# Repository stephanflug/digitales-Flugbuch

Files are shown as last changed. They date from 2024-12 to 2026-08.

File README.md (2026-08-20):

<p align="center">
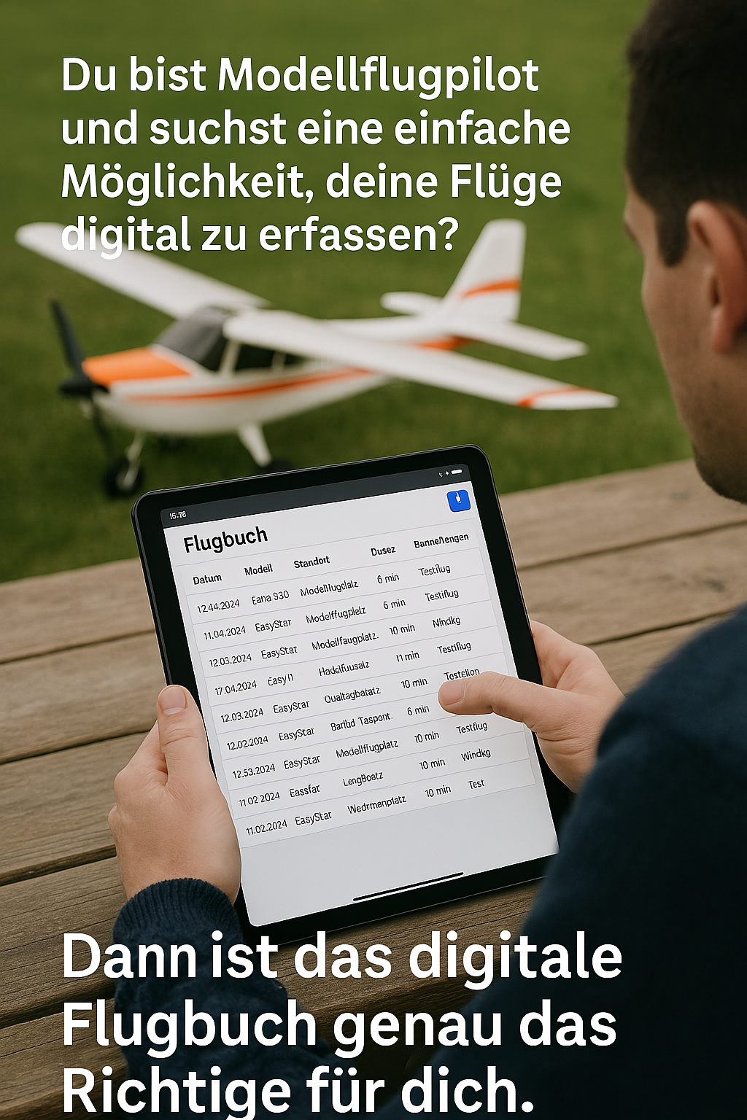
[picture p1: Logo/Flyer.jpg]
  
</p>

<div align="center" width="100%">
    
</div>

# Digitales Flugbuch für Modellflug Vereine

Mit der Software und der Verbindung zu einem Raspberry Pi Zero kann eine digitale Aufzeichnung erstellt werden, die den Anforderungen der aktuellen Verordnung (EU) 2019/947 entspricht.Für Österreich und Deutschland(kann man unter Einstellungen festlegen)

## Kontakt  
Bei Fragen können Sie mich gerne per E-Mail erreichen:  
📧 [steuerung@gmx.at](mailto:steuerung@gmx.at)
oder auch auf dieser Seite [Flugbuch](https://flugbuch.gltdienst.home64.de))

## ⭐ Features

- 🧑‍💼 RFID-Erkennung und Nutzerverifizierung: Wenn ein Benutzer seinen RFID-Chip auf das Lesegerät legt, wird die aktuelle Uhrzeit    zusammen mit dem Namen des Benutzers aus der Benutzerdatei gespeichert. 
- ⌨️ Falls der Benutzer nicht in der Benutzerdatei existiert, wird eine Fehlermeldung ausgegeben.

## ⭐ NEU!

### 🖥️ Flugbuch Cloud Server Panel (Windows) – ab Version 3.9.0

Mit Version **v3.9.0** steht ein neues **Flugbuch Cloud Server Panel für Windows** zur Verfügung.  
Das Panel läuft lokal auf einem Windows-Rechner (z. B. im Vereinsheim) und verbindet sich automatisch mit dem Vereinsflugbuch in der Flugbuch Cloud. Der volle Funktionsumfang des Flugbuchs steht direkt zur Verfügung.

👉 Release-Details:  
https://github.com/stephanflug/digitales-Flugbuch/releases

---

### 🔎 RFID Chip Scanner (Windows & Android)

Zusätzlich zum Flugbuch stehen einfache Hilfstools zum Auslesen der UID von RFID-/NFC-Chips zur Verfügung:

- 🖥️ Windows-Tool für USB-RFID-Lesegeräte  
- 📱 Android-App für NFC-fähige Smartphones  

Die Tools lesen ausschließlich die UID des Chips aus, zeigen sie direkt an und arbeiten vollständig eigenständig.  
Die UID kann im Flugbuch zur eindeutigen Zuordnung von Nutzerchips verwendet werden.

👉 [Zum RFID Chip Scanner](./Tool%20Software/RFID%20Chip%20Scanner/README.md)

---

### 💾 Flugbuch Basic Image

Ein fertiges **Flugbuch Basic Image** steht zum Download bereit.  
Einfach herunterladen und auf die SD-Karte speichern.  
**Bitte unbedingt die Installationsanleitung beachten.**

👉 [Installationsanleitung (PDF)](https://github.com/stephanflug/digitales-Flugbuch/tree/main/Dokumentation/Installation/Flugbuch%20Images)
👉 [Flugbuch Basic Image herunterladen](https://github.com/stephanflug/digitales-Flugbuch/releases)
---

### 📈 Altitude Sensor (ab Version 3.5)

Ab Version **3.5** steht die **Altitude-Sensor-Funktion** zur Verfügung.

👉 [Anleitung (PDF)](https://github.com/stephanflug/digitales-Flugbuch/blob/main/Dokumentation/FlugBuch/RFID%20Flugbuch/Altitude%20Sensor%20beim%20Flugbuch%20einbindenV1.0.pdf)  
👉 Altitude Sensor Projekt: https://github.com/stephanflug/AltitudeSensor

---

### 🧪 Aktuelle getestete Geräte

- ✅ **Pi Zero W2** – getestet  
- ✅ **Pi 3B** – getestet  
- 🔄 **Pi 4** – getestet  
- ⏳ **Pi 5** – getestet

## ⭐ Möglichkeiten:
    -Keinen Cloudzwang
    -Flugbuch-Auswertung direkt auf dem Gerät
    -Möglichkeit, das gesamte Flugbuch zu löschen
    -Flugbuch Einträge bearbeiten
    -Flugbuch-Ausgabe im JSON-Format
    -Flugbuch export in CSV
    -Systeminformationen anzeigen
    -Mail versand
    -Browser Zugang für die Verwaltung
    -Serviceebene direkt auf dem Gerät
    -MQTT
    -MFSD Schnitstelle
    -Kann auch ohne Internet betrieben werden(Nur wenn eine RTC Batterie verbaut wurde)
    -Backup und Restore
    -Viewer Dashboard für eine externen Anzeige via Browser
    -Rest-API Schnitstelle die Flugbuchdaten zu übermitteln
    -Ab der 3.5 Version ist es jetzt möglich einen Altitude Sensor zu verwenden.
    -Bossserver Funktionen.Eine externe Betriebsaufzeichnung auf dem Vereinsserver.
    -VPN Zugang direkt zum Gerät via Flugbuch Cloud Server oder Verein eigenen Server
    -Integration in Areoclub Flugbuch Online
    
<p align="center">
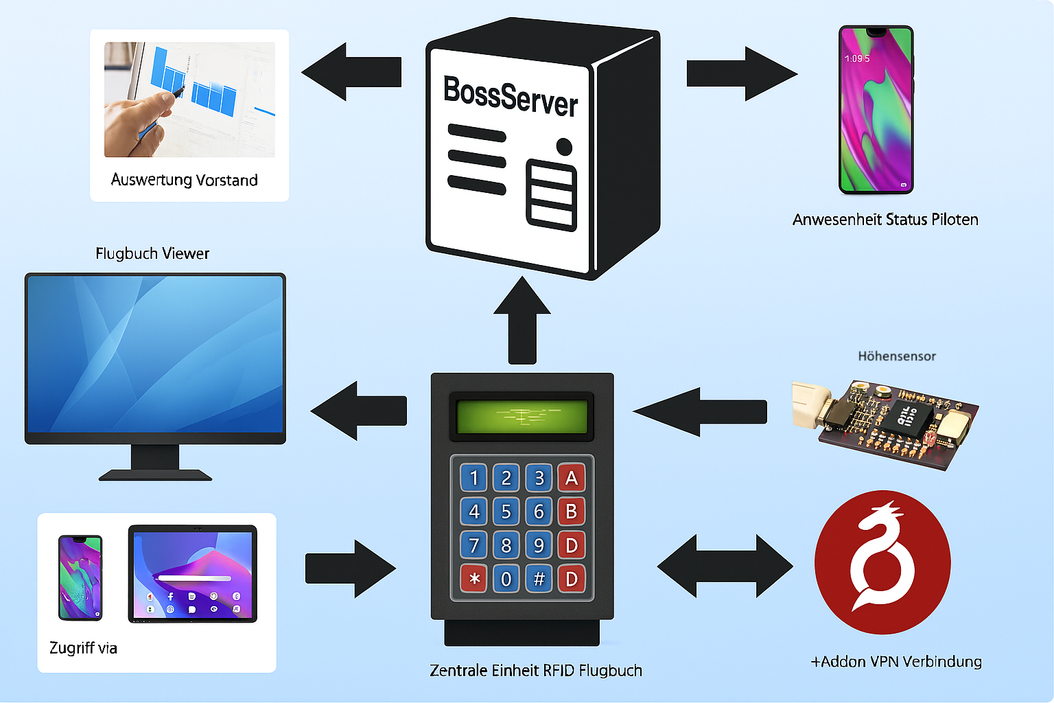
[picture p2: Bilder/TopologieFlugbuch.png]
  
</p>

## 🔧 Vorbereitung: 
```
Benötigte Hardware
- ✅ Raspberry Pi 3 oder höher oder Raspberry Pi 2 Zero. Vereine über 30 User sollten einen Pi 4 verwenden.
- ✅ Speicherkarte (microSD) Kapazität: Mindestens 16 GB, idealerweise 32 GB oder mehr.
- ✅ Ein stabiles und ausreichend starkes Netzteil.
- ✅ Ein Gehäuse 
- ✅ Einen Kühlkörper für den Prozessor.
- ✅ RFID-Modul MFRC522
- ✅ 16-Tasten-Keypad (4x4) mit I2c
- ✅ 1602 LCD-Display mit I2C-Modul
- ✅ RFID-Tags oder -Karten
- ✅ RTC Batterie für den offline Modus(nur wenn das Gerät kein Internet hat)
```
## 🚀 Schnellstart

Verwenden Sie das bereits vorbereitete Image – das spart Zeit und schont die Nerven.

👉 [**Installation: Betriebssystem auf SD-Karte**](https://github.com/stephanflug/digitales-Flugbuch/releases)
👉 [**Doko: Betriebssystem auf SD-Karte**](https://github.com/stephanflug/digitales-Flugbuch/blob/main/Dokumentation/Installation/Flugbuch%20Images/Anleitung_Flugbuch_Images.pdf)  

## 🛠️ Alternative Installation auf einem eigenen Raspberry Pi

Wenn Sie das fertige Image nicht verwenden möchten, können Sie die Software auch manuell auf einem selbst eingerichteten Raspberry Pi installieren.

### ✅ Voraussetzungen

- **Hardware:** Raspberry Pi Zero W2 (oder kompatibles Modell)
- **Betriebssystem:** Vorinstalliertes Linux auf der SD-Karte  
  - **Empfohlen:** Raspberry Pi OS Lite oder Raspberry Pi OS Desktop  
  - **Alternativen:** Ubuntu MATE, DietPi, Arch Linux (sofern kompatibel mit Raspberry Pi)
  -  Speichermedium (SD-Karte) Hochwertige SD-Karte (z. B. SanDisk High Endurance oder Samsung Pro Endurance).

### 📦 Vorbereitung

#### 1. Betriebssystem installieren

Falls noch kein Betriebssystem installiert ist:

- Laden Sie den [**Raspberry Pi Imager**](https://www.raspberrypi.com/software/) herunter.
- Wählen Sie ein geeignetes Linux-Betriebssystem (z. B. Raspberry Pi OS).
- Installieren Sie es auf die SD-Karte.

👉 Eine Schritt-für-Schritt-Anleitung finden Sie in der [offiziellen Raspberry Pi-Dokumentation](https://www.raspberrypi.com/documentation/computers/getting-started.html).

#### 2. Raspberry Pi einrichten

- SD-Karte in den Raspberry Pi einlegen
- Monitor, Tastatur und Maus anschließen
- Gerät starten und überprüfen, ob das System korrekt läuft
- Internetverbindung sicherstellen (WLAN oder Ethernet)

> ⚠️ **Hinweis:** Ohne ein vorinstalliertes Linux-Betriebssystem kann dieses Projekt nicht ausgeführt werden. Bitte stellen Sie sicher, dass das System korrekt installiert und betriebsbereit ist, bevor Sie fortfahren.

###
1. Vorbereitungen nur wenn Docker noch nicht auf dem System installiert wurde sonst weiter mit Postion 3
###  
Als Video ansehen:    <a href="https://github.com/stephanflug/digitales-Flugbuch/blob/main/Installation/Neuinstallation/Video/InstallationVideoFlugBuchsoftware.mp4" target="_blank">Video</a>

Aktualisiere das System:
```
sudo apt update
sudo apt upgrade -y
```

Die empfohlene Methode zur Installation von Docker auf einem Raspberry Pi ist die Verwendung des offiziellen Installationsskripts von Docker, das alle notwendigen Repositorys und Schritte berücksichtigt. 
```
curl -fsSL https://get.docker.com -o get-docker.sh
```
```
sudo sh get-docker.sh
```

2. Docker-Dienst aktivieren
```
sudo systemctl start docker
```
```
sudo systemctl enable docker
```
3.Verzeichniss erstellen für script
```
sudo mkdir -p /opt/digitalflugbuch
```
4.Wechsel dann in das Verzeichnis:
```
cd /opt/digitalflugbuch
```

5a. Herunterladen des Skripts mit wget mit Raspberry Pi 3/4/5 Zero 2W oder höher: Prozessor ARMV7
```
sudo wget -O script.sh https://raw.githubusercontent.com/stephanflug/digitales-Flugbuch/main/script_armv7.sh
```

6. Anmeldeung als root Benutzer wenn das Passwort noch nicht gesetzt wurde mit sudo passwd root
```
su
```

6. Script ausführen.
```
sudo bash script.sh
```
7.Raspi-Config aufrufen
```
sudo raspi-config
```
Menüoptionen von raspi-config
> Interface Options
>Aktivierung von Schnittstellen wie  I2C, SPI

8.Gerät neustarten
```
sudo reboot
```

Beispielablauf:
Das Skript wird heruntergeladen und im aktuellen Verzeichnis gespeichert.
Es wird ausführbar gemacht, sodass du es wie ein Programm starten kannst.
Schließlich wird das Skript ausgeführt, und es erledigt alle im Code definierten Aufgaben.

9. Status prüfen:
```
sudo docker ps
```

10. Danach können Sie die Verwaltungsseite öffnen.
```
Startseite url:http://<IPAdresse>:1880/home
```

11 Schaltplan Prinzipschema:   <a href="https://github.com/stephanflug/digitales-Flugbuch/blob/main/Schaltplan/BelegungsaufstellungV1.0.pdf" target="_blank">Belegungsaufstellung</a>

11a Version 1 mit RFID RC522 (alte Version. Empfehlung:Bei Neuinstallation Version 2 zu verwenden)
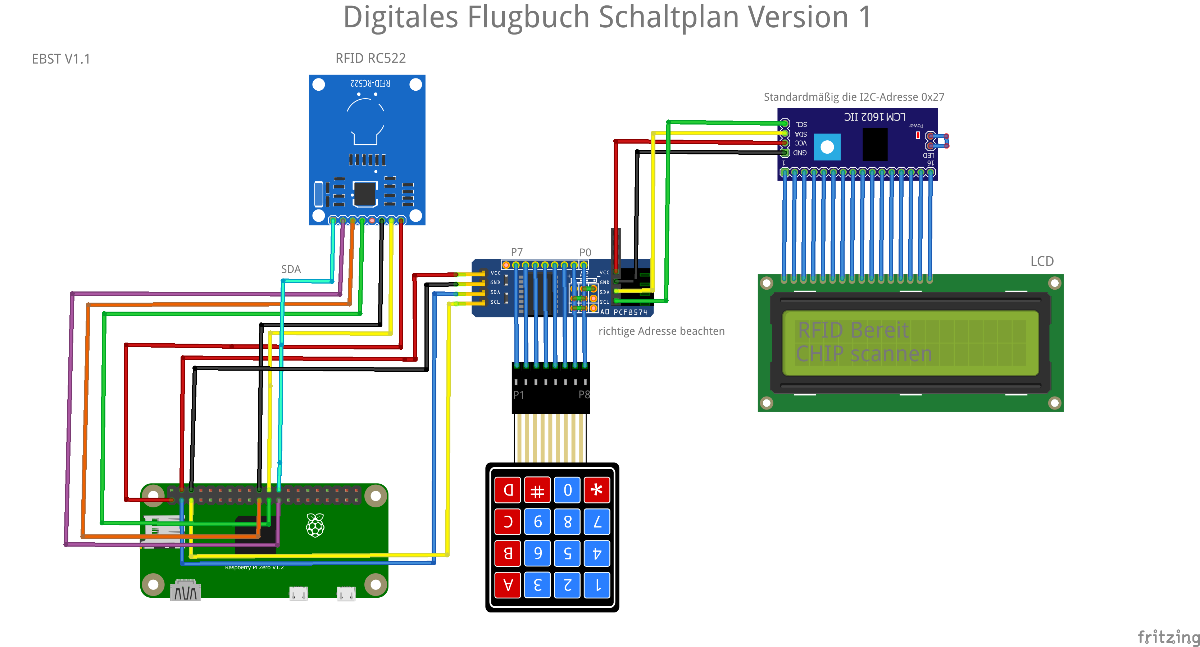
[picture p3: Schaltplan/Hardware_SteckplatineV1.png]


11b Version 1B mit RFID RC522 + RTC
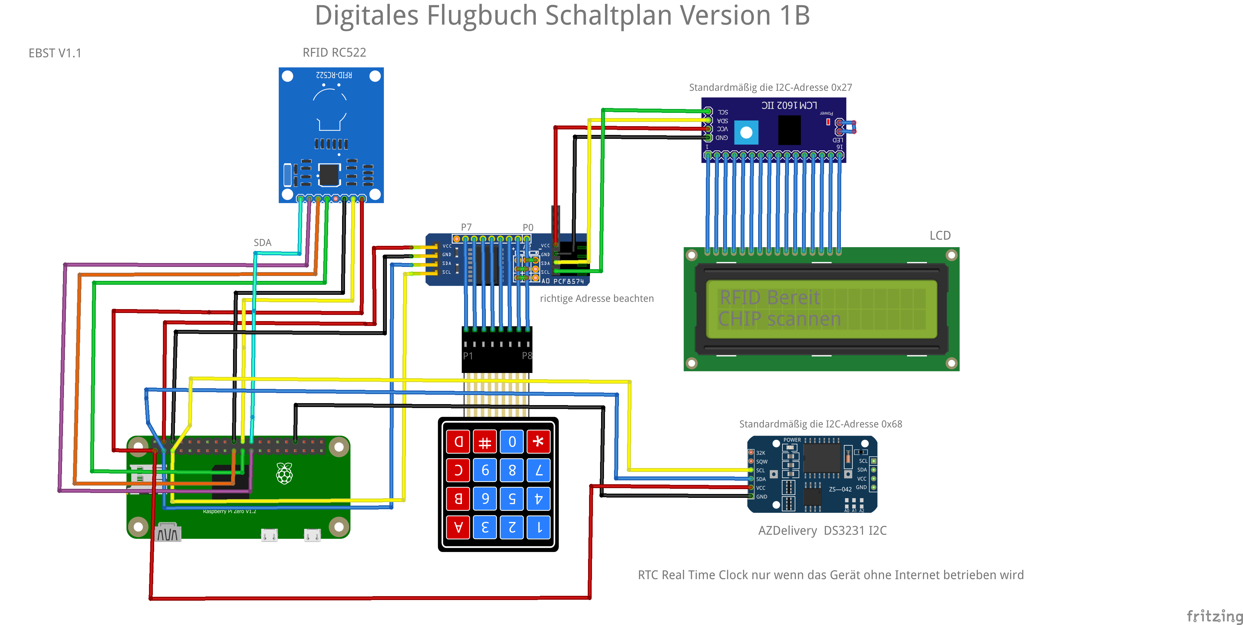
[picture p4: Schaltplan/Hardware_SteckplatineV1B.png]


11c Version 2 mit RFID PN532 + (RTC muss man nicht ausführen wenn das Gerät Internet Zugang hat)
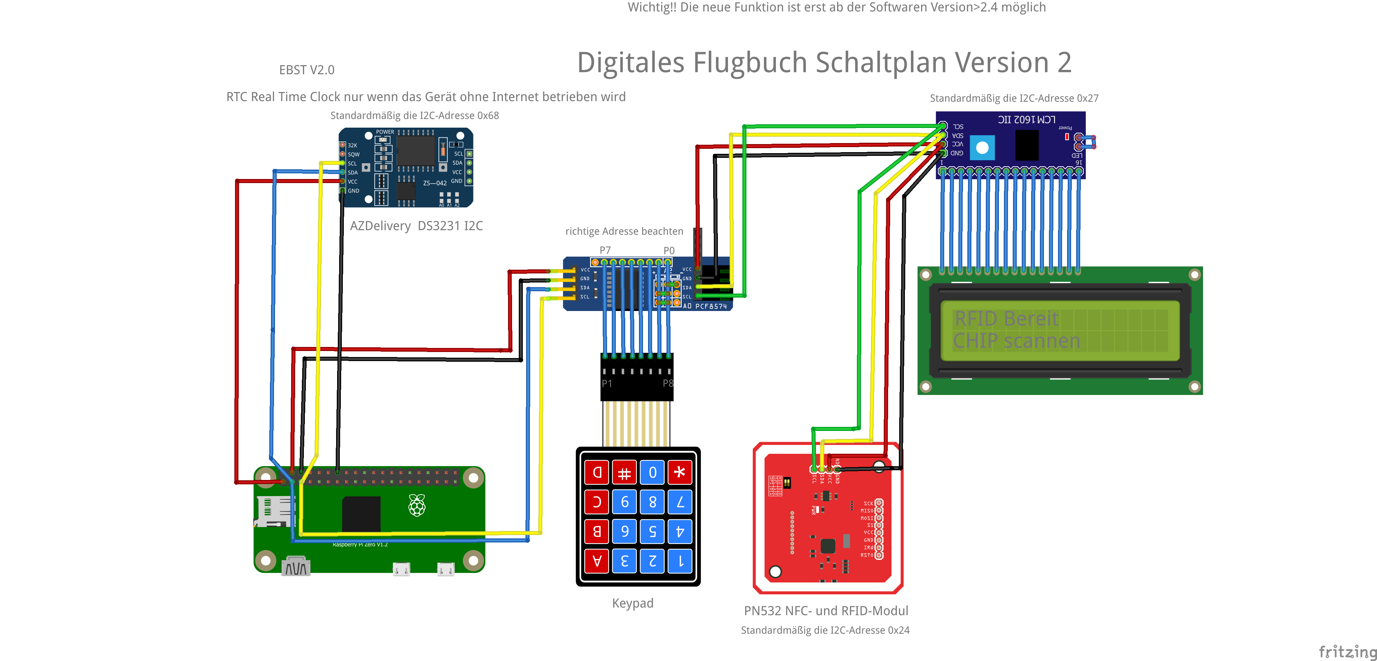
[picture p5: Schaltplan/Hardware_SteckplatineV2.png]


12. Zugriff via Browser: Weitere Bilder Hier: <a href="https://github.com/stephanflug/digitales-Flugbuch/tree/main/Bilder/Webbedienung" target="_blank">Bilder</a>

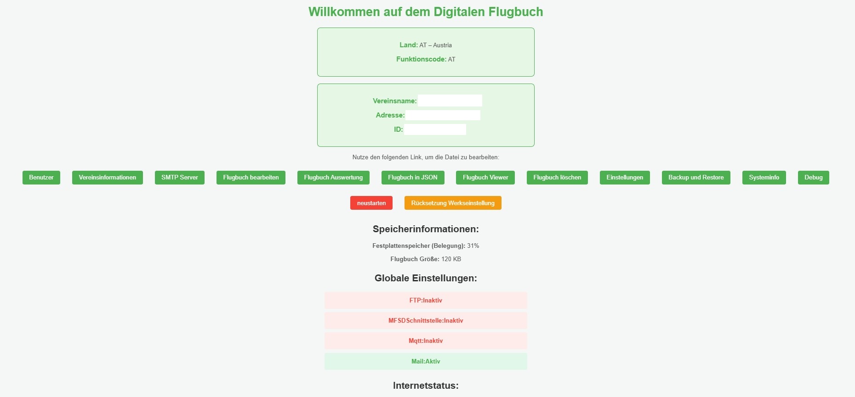
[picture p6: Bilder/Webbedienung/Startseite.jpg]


13. Videos:
<a href="https://www.youtube.com/shorts/2yrWCz5p4jw" target="_blank" rel="noopener noreferrer">
    YouTube Video
</a>

<a href="https://youtu.be/VoY1FuDAuMs" target="_blank" rel="noopener noreferrer">
    YouTube Video
</a>

<a href="https://youtube.com/shorts/nOOInCLnYMw" target="_blank" rel="noopener noreferrer">
    YouTube Video
</a>

<a href="https://youtube.com/shorts/AbHP6MEdS38" target="_blank" rel="noopener noreferrer">
    YouTube Video
</a>

###
1.1 Neues Update einspielen

Hinweis: Wenn Sie bereits das fertige Image verwenden, müssen Sie lediglich die IP-Adresse des Geräts in den Browser eingeben. Sie gelangen dann direkt zur Grundkonfiguration, in der Sie im Menü den Punkt „Flugbuch-Update“ finden.
Diese Schritte sind in diesem Fall nicht mehr erforderlich.

1.2 Wechsel in das Verzeichnis:
```
cd /opt/digitalflugbuch
```
1.3 Herunterladen des Skripts
```
sudo wget -O update_script.sh https://raw.githubusercontent.com/stephanflug/digitales-Flugbuch/main/update_script_armv7.sh
```
1.4  Anmeldeung als root Benutzer
```
su
```

1.5. Script ausführen.
```
sudo bash update_script.sh
```
1.6.Gerät neustarten
```
sudo reboot
```

### ☕ Unterstütze das Büro-Kaffeekonto!

Damit der Kaffee im Büro nie ausgeht und die Entwicklung weiter auf Hochtouren läuft, freuen wir uns über eine kleine Unterstützung. ☕💻

Jeder Beitrag hilft dabei, die Kaffeemaschine am Laufen zu halten und sorgt für genügend Energie für neue Ideen, Funktionen und Updates.



**☕ [Kaffee via PayPal spendieren](https://paypal.me/stephanflug)**

Vielen Dank für deine Unterstützung! ❤️

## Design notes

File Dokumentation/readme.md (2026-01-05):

# RFID-Flugbuch – Dokumentation

Dieses Repository dient als zentrale Anlaufstelle für Hinweise, Releases und Verweise rund um das **RFID-Flugbuch** (inkl. Service-Menü, Systemkonfiguration, Add-ons und Inbetriebnahme).

Die **vollständige Dokumentation** finden Sie hier:

## 📚 Online-Dokumentation
👉 https://doko.flugbuch.gltdienst.home64.de/share/hiv8kxsvqf/p/servicemenue-geraet-xMON4uZUVv

---

## Inhalt (Kurzüberblick)
In der Online-Dokumentation finden Sie unter anderem:

- **Gerätebedienung** (Anmeldung/Abmeldung, Eingaben über Keypad)
- **Service-Menü** (Statusanzeigen, IP, WLAN, Version, Neustart, Sensoranzahl)
- **Weboberfläche / Admin-Funktionen** (Benutzer, Vereinsdaten, Flugbuch-Management, Auswertung, Backup/Restore)
- **Add-ons** (z. B. WireGuard-Client, Healthcheck, Systemupdate)
- **Altitude Sensor** (Einbindung via MQTT, Prüfung im Service-Menü)
- **Inbetriebnahme & Debug** (I²C-Scan, Systemwerte, Diagnose)

---

## Änderungen / Releases
Änderungen und Versionen werden über die GitHub-Releases bzw. die Dokumentation nachvollziehbar gemacht.

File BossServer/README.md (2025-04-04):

# **Flugdaten Auswertungs- und Login-System**

Dieses Projekt umfasst zwei wesentliche Komponenten: ein sicheres **Login-System** und eine **Flugdaten-Auswertungsseite**. Die Benutzer können sich anmelden, um auf Flugdaten zuzugreifen und diese zu analysieren. 

## **Code 1: Login-System**

Das Login-System gewährleistet einen sicheren Zugriff auf die Flugdaten. Benutzer müssen sich mit einem Benutzernamen und Passwort anmelden, bevor sie auf die Auswertungsseite zugreifen können. 

### **Funktionen:**
- **Sichere Session-Verwaltung:** 
  - Erneuert die Session-ID nach dem Login, um Session-Hijacking zu verhindern.
  - Stellt sicher, dass die Cookies nur über HTTPS gesendet werden und JavaScript nicht darauf zugreifen kann.
- **Benutzerauthentifizierung:** 
  - Überprüft Benutzernamen und Passwort gegen eine vordefinierte Liste in einer externen Datei (`users.php`).
  - Bei erfolgreichem Login wird der Benutzer zur Seite mit den Flugdaten weitergeleitet. Bei Fehlern wird eine Fehlermeldung angezeigt.
- **Responsives Design:** 
  - Ein benutzerfreundliches Login-Formular, das auf allen Geräten gut aussieht.

### **Verwendete Technologien:**
- PHP für die Server-seitige Logik.
- HTML, CSS für das Frontend.

---

## **Code 2: Flugdaten Auswertung und Filterung**

Nach dem erfolgreichen Login können Benutzer Flugdaten einsehen, filtern und analysieren. Diese Seite bietet eine detaillierte Auswertung der Flugdaten, basierend auf RFID und Benutzernamen.

### **Funktionen:**
- **Zugriffsprüfung:** 
  - Stellt sicher, dass nur angemeldete Benutzer auf die Auswertungsseite zugreifen können.
- **Datenanalyse:** 
  - Flugdaten werden aus mehreren JSON-Dateien geladen und zusammengeführt.
  - Eine statistische Auswertung zeigt die Anzahl der Flüge pro Benutzer.
  - Detaillierte Informationen zu jedem Flug wie Startzeit, Endzeit und Flughöhe werden angezeigt.
- **Filterfunktionen:** 
  - Ermöglicht das Filtern der Flugdaten nach **RFID** und **Benutzernamen**.
- **Grafische Darstellung:** 
  - **Chart.js** wird verwendet, um die Anzahl der Flüge pro Benutzer in einer interaktiven Balkengrafik darzustellen.
- **PDF-Export:** 
  - Die Möglichkeit, die Flugdaten und die erstellte Grafik als PDF herunterzuladen.

### **Verwendete Technologien:**
- PHP für die Backend-Logik.
- **Chart.js** für die Erstellung interaktiver Diagramme.
- **jsPDF** für den Export von Daten als PDF.

---

## **Technische Details und Anforderungen**

### **Sicherheitsvorkehrungen im Login:**
- **Session-Hijacking-Schutz:** 
  - Das Session-Cookie ist **HTTPOnly** und wird nur über **HTTPS** gesendet.
  - **Session-Regenerierung** sorgt dafür, dass die Session-ID nach der Anmeldung geändert wird.
  
### **Flugdatenverarbeitung:**
- Die Flugdaten werden aus Dateien im JSON-Format geladen und aufbereitet.
- **RFID- und Benutzernamenfilter:** 
  - Ermöglicht das gezielte Filtern von Flugdaten basierend auf RFID und Benutzernamen.
  
### **Datenvisualisierung:**
- Mit **Chart.js** werden Flugdrafiken erstellt, um die Verteilung der Flüge übersichtlich darzustellen.
- Die Tabelle zeigt detaillierte Fluginformationen, einschließlich **Flughöhe** und **Luftraumbeobachter**.

---

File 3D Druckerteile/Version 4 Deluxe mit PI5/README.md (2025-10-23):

# 📦 Raspberry Pi 5 Gehäuse mit digitalem Flugbuch & RFID-Chip

Ein maßgeschneidertes Gehäuse für den **Raspberry Pi 5** – optimiert für den Einsatz mit dem **digitalen Flugbuch** und integriertem **RFID-Chip**.  
Optional mit **PG16-Kabeldurchführung** (oben oder unten).

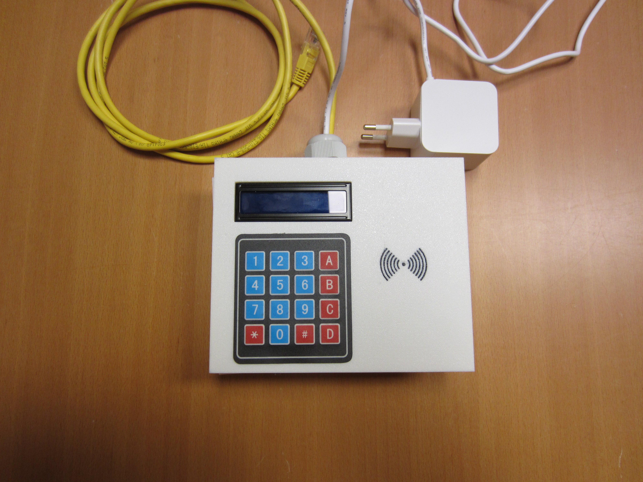
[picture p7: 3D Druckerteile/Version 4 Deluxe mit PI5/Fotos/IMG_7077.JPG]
Gehäuse mit RFID und Display


---

## ⚙️ Features

📗 Passend für Raspberry Pi 5  
📘 Öffnungen für Display und RFID-Modul  
🔩 PG16-Kabeldurchführung wahlweise oben oder unten  
🧊 Kompatibel mit Einschmelzmuttern (M2 × 4 mm)  
🖨️ Optimiert für FDM-Druck mit PETG oder PLA  

---

## 🔧 Hinweise zur Montage

### 🕳️ Bohrungen & Befestigung
- 🔩 **4 × Schrauben Ø 4–4,5 mm** – zur Gehäusemontage  
- 🧷 **M2 × 4 mm Einschmelzmuttern** – für Innenbefestigungen  
- ⚙️ Einschmelzmuttern bei *Deckel 1* **nicht möglich** (durchgehende M2-Schrauben verwenden)

---

### 🧱 Material & Druckparameter
- **Material:** PETG (Außenmontage) oder PLA (Innenmontage)  
- **Drucker:** Bambu Lab P1S / X1C mit AMS  
- **Layerhöhe:** 0,2 mm  
- **Infill:** 20–30 %  
- **Supports:** Nur bei Bedarf  

---

## 🧩 STL-Dateien

### 🔖 Logo
- `Logo.stl`

### 🧱 Gehäuseboden
- `Gehäuse_PG16_oben.stl`  
- `Gehäuse_PG16_unten.stl`

### 🧰 Gehäuse 1 – Deckel
- 📺 **Display-Ausschnitt:** 73,5 mm × 27,5 mm  
- 🔩 **4 × M2-Schrauben (durchgehend)**  
- `Deckel_1_mit_Logo.stl`  
- `Deckel_1_ohne_Logo.stl`

### 🧰 Gehäuse 2 – Deckel
- 📺 **Display-Ausschnitt:** 71,5 mm × 25,0 mm  
- `Deckel_2_mit_Logo.stl`  
- `Deckel_2_ohne_Logo.stl`

### 🧰 Gehäuse 3 – Deckel
- 📺 **Display-Ausschnitt:** 72,0 mm × 25,8 mm  
- `Deckel_3_mit_Logo.stl`  
- `Deckel_3_ohne_Logo.stl`

---

## 🧑‍🔬 Autor

Erstellt und getestet von **Thomas Behmer** 🛠️

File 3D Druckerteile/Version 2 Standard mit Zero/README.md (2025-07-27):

# 📦 Raspberry Pi Zero W2 Gehäuse mit RFID und Display

Ein maßgeschneidertes Gehäuse für den Raspberry Pi Zero W2 – mit Halterungen für ein RFID-Modul, ein Display sowie Belüftung für einen Kühlkörper.

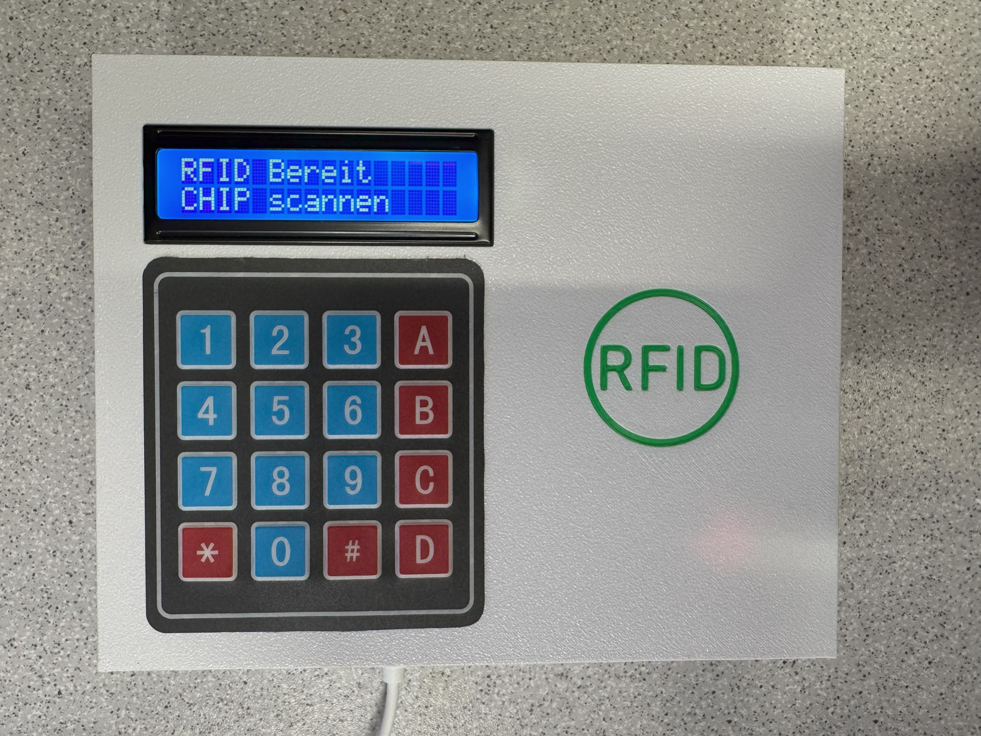
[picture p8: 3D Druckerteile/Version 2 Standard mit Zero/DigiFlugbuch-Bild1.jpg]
Gehäuse mit RFID und Display


---

## ⚙️ Features

📗 Platz für Raspberry Pi (mit Kühlkörper)  
📘 Montagemöglichkeiten für RFID-Modul & Display  
🧊 Kompatibel mit Geekworm-Kühlkörpern  
🧷 Unterstützung für eingeschmolzene Gewindeeinsätze  
🖨️ Optimiert für FDM-Druck mit PETG  

---

## 🔧 Hinweise zur Montage

### 🕳️ Bohrungen
- 🔩 **M3** – für RFID-Modul, Display und Gehäusedeckel  
- 🔩 **M2.5** – zur Befestigung des Raspberry Pi mit Kühlkörper  

### 🧊 Kühlkörper
Ich verwende diesen Kühlkörper von Geekworm (Amazon):  
👉 `B09QMBCXLB` auf Amazon

### 🖨️ 3D-Druck
- Material: **PETG**  
- Drucker: **Bambu Lab P1S mit AMS**  
- Layerhöhe: **Empfohlen: 0.2 mm**  
- Infill: **15–25 %**  
- Supports: **Nur bei Bedarf**  

Die Schrauben werden direkt ins Material eingedreht (alternativ Gewindeeinsätze verwenden).

---

## 🔥 Gewindeeinsätze (eingeschmolzen)
- 🧷 **M2.5** – für die Befestigung des Raspberry Pi  
- 🧷 **M3** – zur Verschraubung des Gehäusedeckels  

---

## 🧑‍🔬 Autor

Erstellt und getestet von **Christoph Figl** 🛠️

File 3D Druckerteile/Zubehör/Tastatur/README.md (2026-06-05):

# Tastatur-Abdeckung für 4x4 Matrix-Keypad

Dieses Verzeichnis enthält eine 3D-druckbare Abdeckung für eine 4x4 Matrix-Tastatur. Die Abdeckung ist als Zubehör für das digitale Flugbuch gedacht und kann zur sauberen Montage eines 16-Tasten-Keypads verwendet werden.

## Dateien

| Datei | Beschreibung |
|---|---|
| [`Tastatur Abdeckung.stl`](./Tastatur%20Abdeckung.stl) | STL-Datei für den 3D-Druck der Tastatur-Abdeckung. |
| [`4x4_Keypad_Tastatur_Datenblatt_AZ-Delivery_Vertriebs_GmbH.pdf`](./4x4_Keypad_Tastatur_Datenblatt_AZ-Delivery_Vertriebs_GmbH.pdf) | Datenblatt des verwendeten 4x4 Matrix-Keypads mit technischen Daten, Pinout und Anschlussbeispielen. |

### Anschlussbelegung

| Alter Anschluss / Steuerung | Neue 4x4-Tastatur |
|---:|---:|
| 1 | 5 |
| 2 | 6 |
| 3 | 7 |
| 4 | 8 |
| 5 | 1 |
| 6 | 2 |
| 7 | 3 |
| 8 | 4 |



## Verwendungszweck

Die Abdeckung dient dazu, das 4x4 Keypad mechanisch sauber in ein Gehäuse oder Bedienfeld zu integrieren

## Montage

1. STL-Datei im Slicer öffnen.
2. Druckausrichtung und Skalierung prüfen.
3. Abdeckung drucken.
4. Druckteil entgraten und Passform mit dem Keypad testen.
5. Keypad einsetzen und mechanisch befestigen.
6. Anschlussleitungen gemäß Pinout oder eigenem Schaltplan verbinden.
7. Funktionstest jeder Taste durchführen.

## Sicherheitshinweise

- Vor dem Anschluss Spannungsversorgung trennen.
- Keine GPIO-Pins des Raspberry Pi mit 5 V oder 24 V beaufschlagen.
- Pinout vor dem Einschalten prüfen.
- Kurzschlüsse durch offene Kontakte oder falsch gesteckte Leitungen vermeiden.

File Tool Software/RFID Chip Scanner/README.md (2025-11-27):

# 🔎 RFID Chip Scanner – Windows & Android

## 📘 Übersicht

Dieser Ordner enthält zwei kompakte Hilfstools, die ausschließlich dazu dienen, die **UID (Unique ID) von RFID-Chips** auszulesen:

- 🖥️ **Windows-Tool** für USB-RFID-Lesegeräte  
- 📱 **Android-App** für NFC-fähige Smartphones  

Die ermittelten UID-Werte können unter anderem im **Digitalen Flugbuch** verwendet werden, um Nutzerchips eindeutig zuzuordnen. Die Tools arbeiten **komplett eigenständig** und greifen **nicht** auf das Flugbuchsystem zu.

---

## 🎯 Funktionsumfang

- 🔐 Auslesen der **UID** eines RFID-Chips  
- 👁️ Klare, direkte Anzeige der UID  
- 📋 Möglichkeit zum Kopieren oder Notieren der UID  

> ℹ️ Beide Tools sind bewusst schlicht gehalten und fokussieren sich auf zuverlässiges, unkompliziertes UID-Auslesen.

---

## 🖥️ Windows-Tool

### Eigenschaften
- ✔️ Unterstützt Windows 10 und 11  
- ✔️ Funktioniert mit gängigen **USB-RFID-Readern**  

### Anwendung
1. 🔌 USB-RFID-Leser anschließen  
2. ▶️ Windows-Tool starten  
3. 🪪 RFID-Chip auflegen  
4. 📄 UID wird sofort angezeigt  

---

## 📱 Android-App

### Eigenschaften
- ✔️ Für Android-Geräte mit **NFC-Unterstützung**  
- ✔️ Nutzt den integrierten NFC-Sensor des Smartphones  

### Anwendung
1. 📥 App installieren  
2. 📡 NFC aktivieren  
3. ▶️ App starten  
4. 🪪 Chip an die Rückseite des Geräts halten  
5. 📄 UID erscheint direkt auf dem Display  

---

## 👨‍💻 Softwareentwicklung

**Entwickelt von: Thomas Behmer**

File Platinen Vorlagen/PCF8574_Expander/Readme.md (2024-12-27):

Platinen-Layout ist mit "Eagle 7" gemacht , die e12 Datei im Isolationsfräsen mit "Estlcam 12"

von Manfred Stratmann

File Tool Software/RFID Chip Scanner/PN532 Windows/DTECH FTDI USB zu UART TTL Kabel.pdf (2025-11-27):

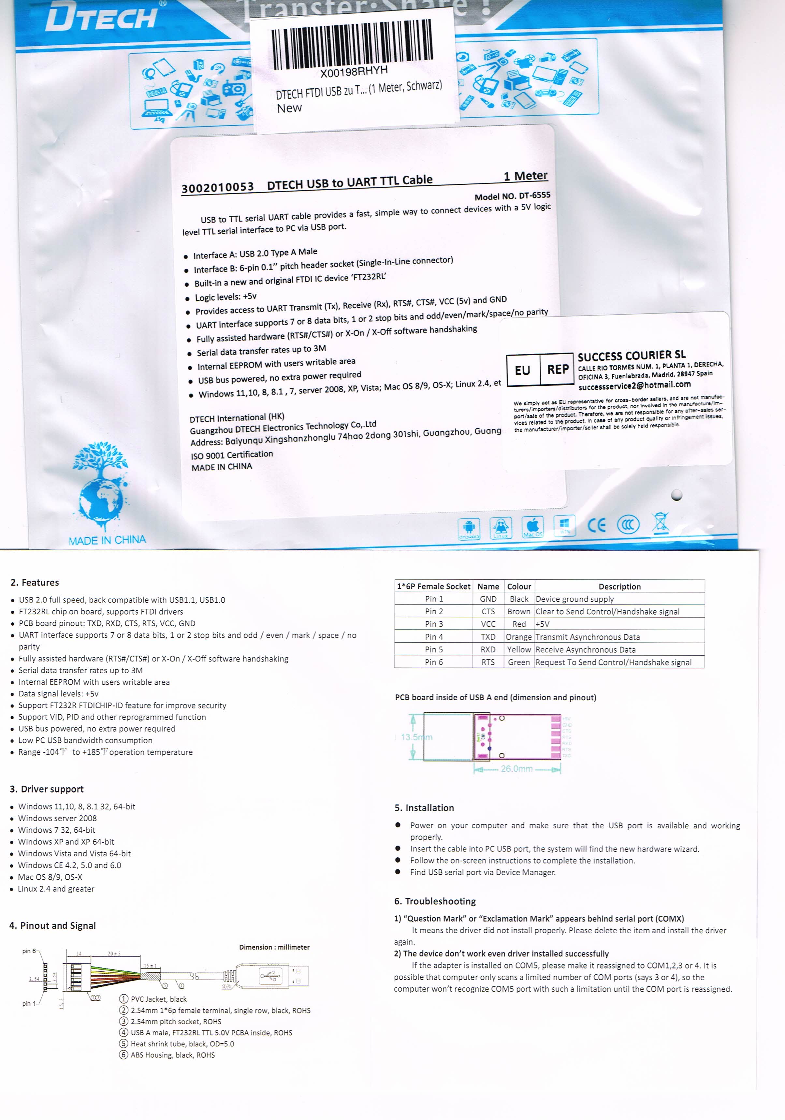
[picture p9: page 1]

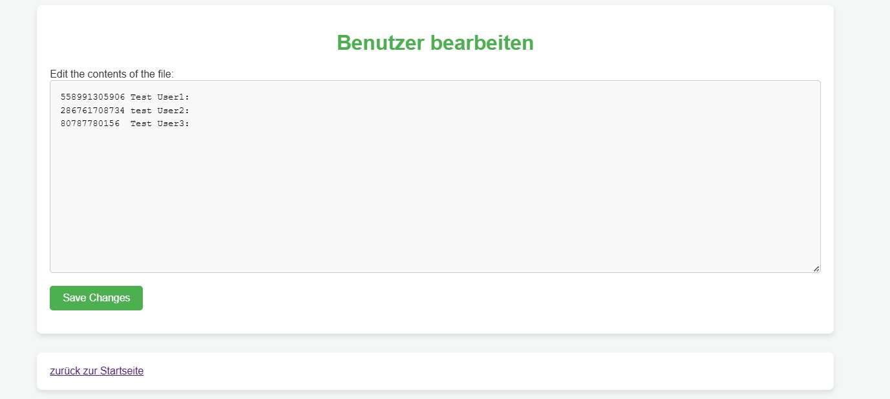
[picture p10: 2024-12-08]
Bilder/Webbedienung/Benutzer.jpg

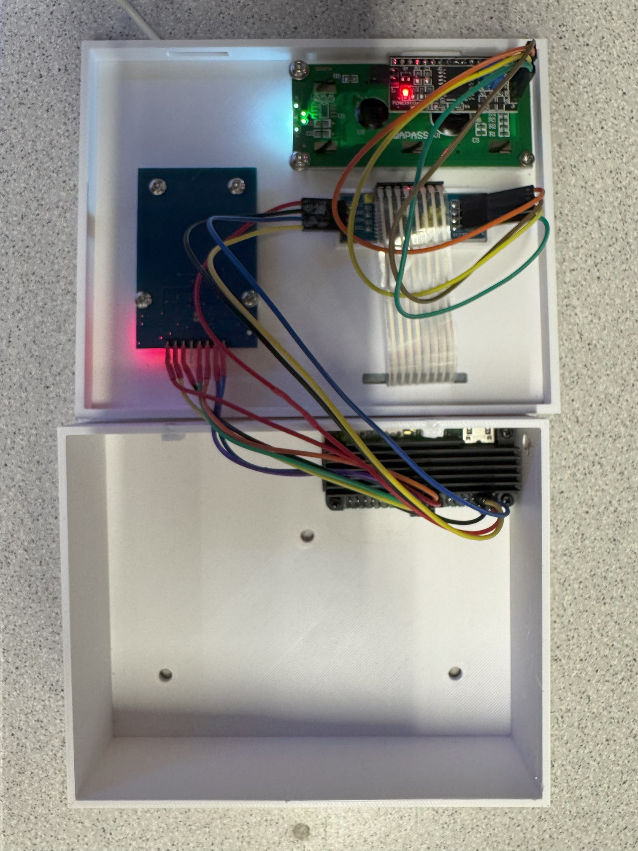
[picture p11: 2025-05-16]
3D Druckerteile/Version 2 Standard mit Zero/DigiFlugbuch-Bild2.jpg

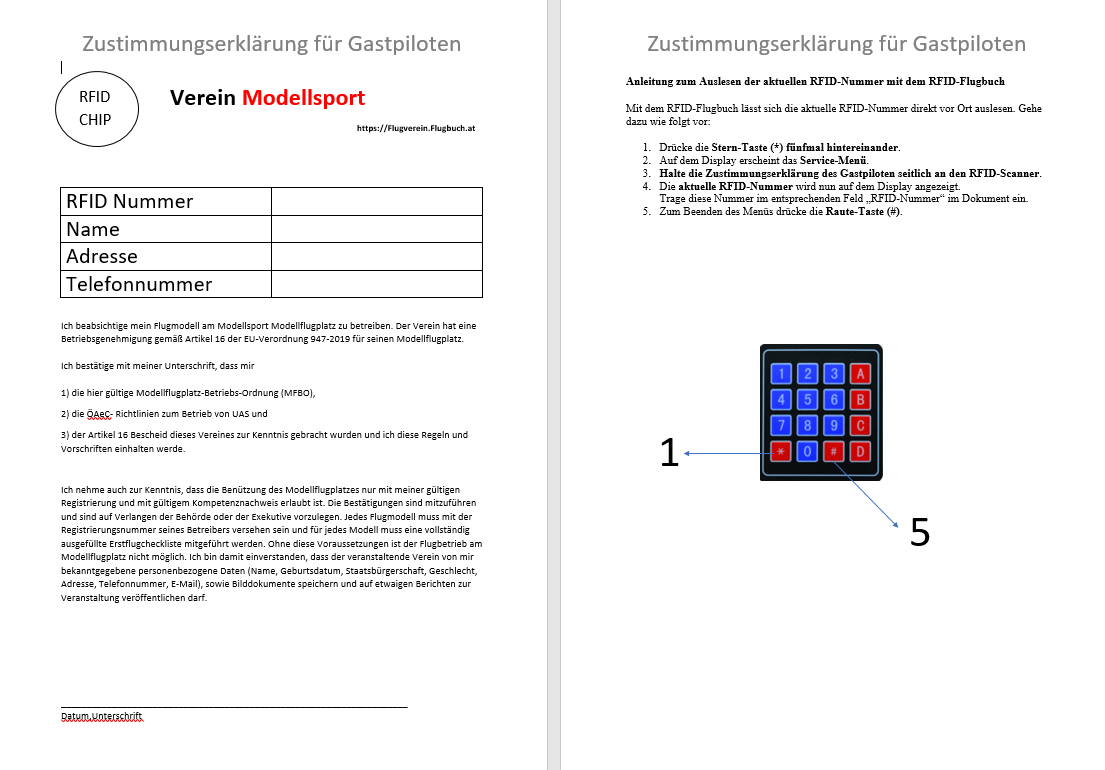
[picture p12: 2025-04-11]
Formulare/Gastpiloten/Bild Formular Gastpilot.png

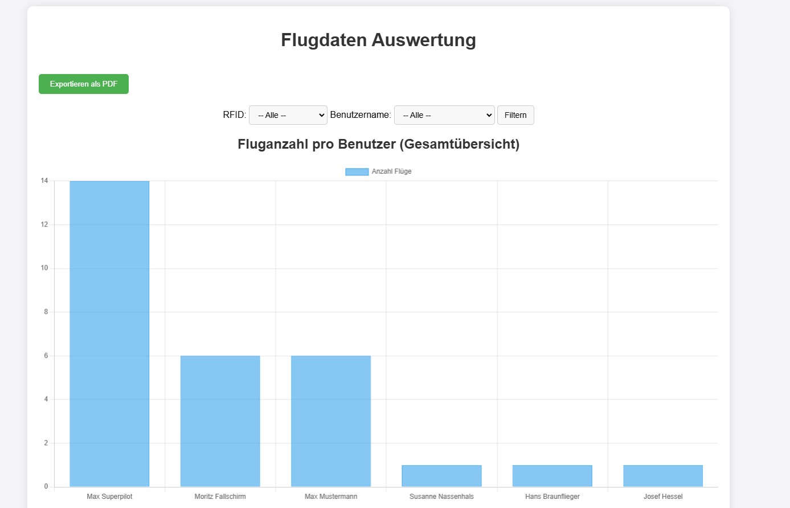
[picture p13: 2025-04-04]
BossServer/V1/Bilder/Flugdaten Auswertung.jpg

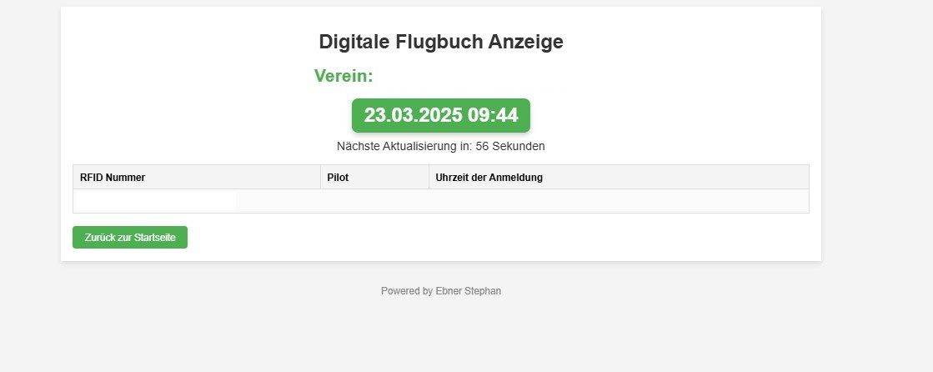
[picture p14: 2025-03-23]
Bilder/Webbedienung/Flugbuch Viewer.jpg

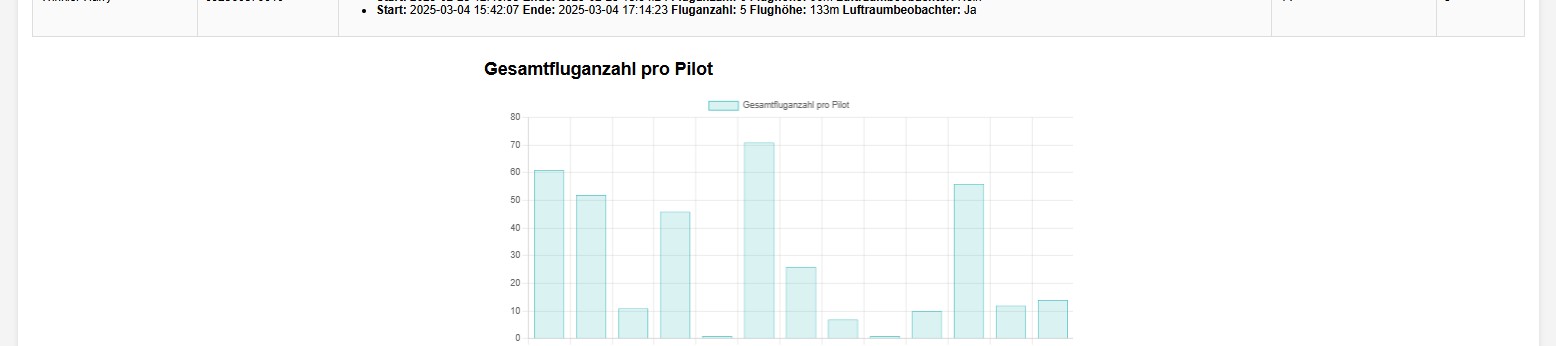
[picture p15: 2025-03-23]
Bilder/Webbedienung/Flugbuch Auswertung_2.jpg

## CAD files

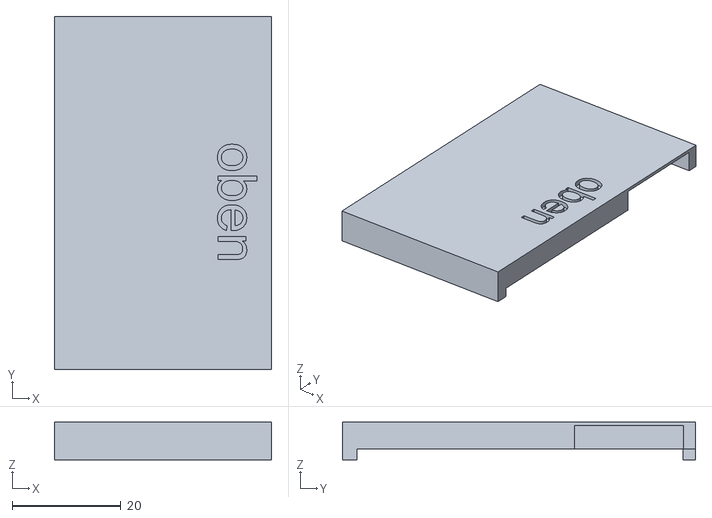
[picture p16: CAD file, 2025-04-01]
3D Druckerteile/Version 1 Basic mit Zero/RC522V1.stl
40.0 x 65.0 x 6.94

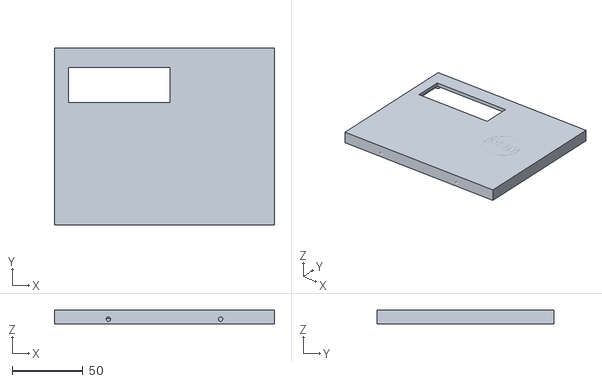
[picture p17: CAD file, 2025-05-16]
3D Druckerteile/Version 2 Standard mit Zero/DigiFlugbuch Oberteil.stl
155.0 x 125.0 x 10.0

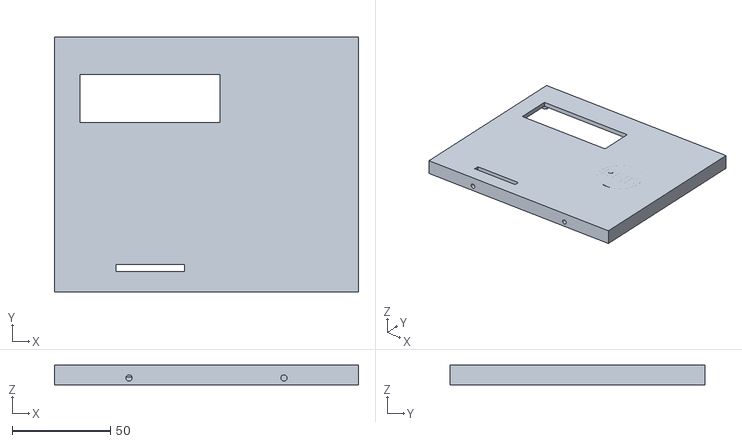
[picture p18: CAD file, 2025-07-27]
3D Druckerteile/Version 3 Deluxe mit PI4/DigiFlugbuch Rpi4 outdoor Deckel.stl
155.0 x 130.0 x 10.0

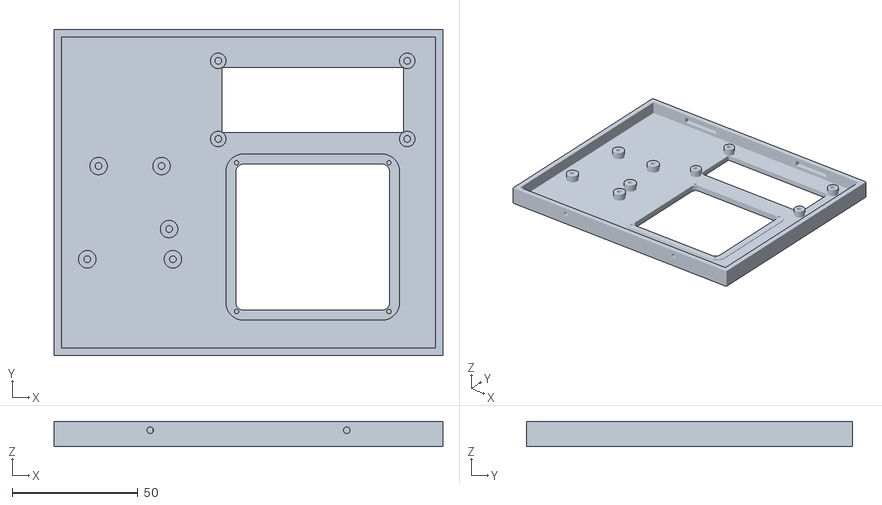
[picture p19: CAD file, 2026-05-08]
3D Druckerteile/Version 4 Deluxe mit PI5/Deckel_3_angepasst_neue_Tastatur.stl
154.4 x 129.4 x 10.0

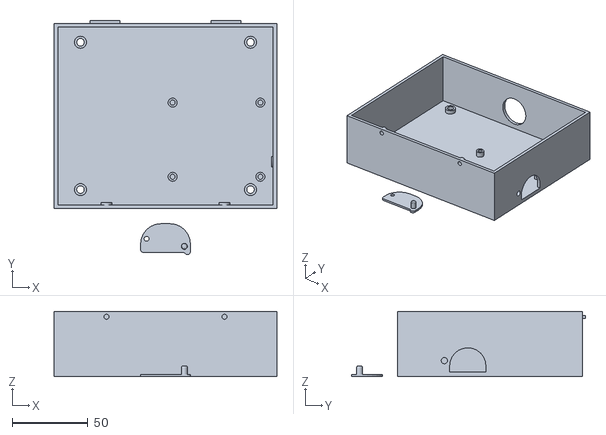
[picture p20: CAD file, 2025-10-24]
3D Druckerteile/Version 4 Deluxe mit PI5/mit SD Karten Serviceklappe/Gehäuse_PG16_oben+.stl
147.4 x 154.9 x 43.0

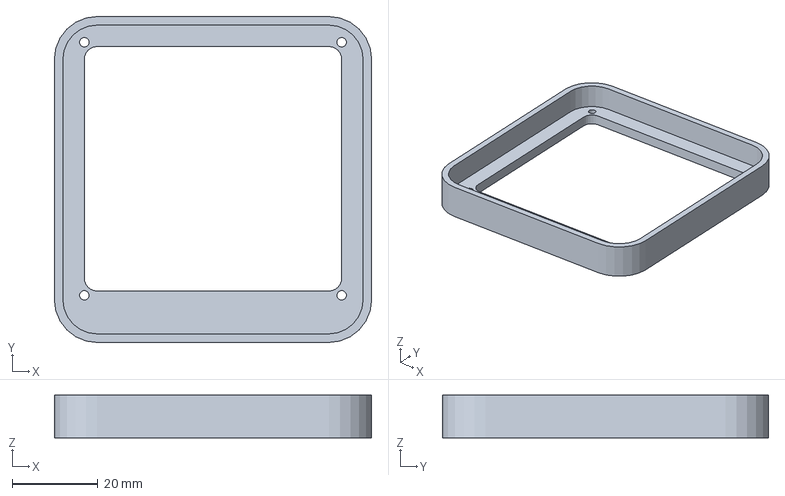
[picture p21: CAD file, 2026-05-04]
3D Druckerteile/Zubehör/Tastatur/Tastatur Abdeckung.3mf
74.0 x 76.0 x 10.0 mm

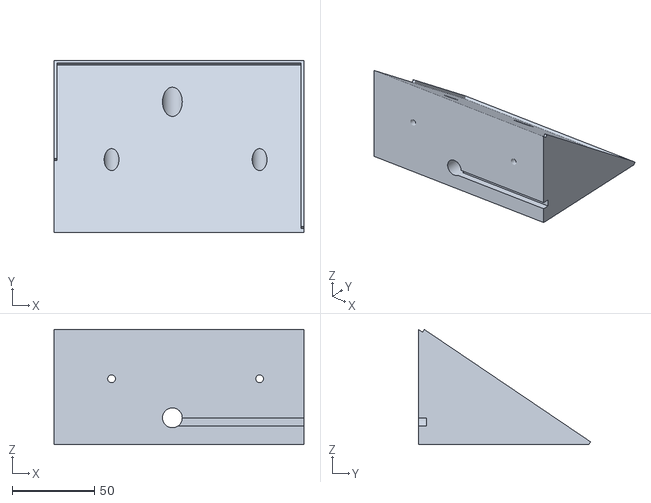
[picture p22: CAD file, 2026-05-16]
3D Druckerteile/Zubehör/Wandhalterung/Flugbuch-Pi4-Wandhalterung.stl
152.0 x 104.7 x 70.0

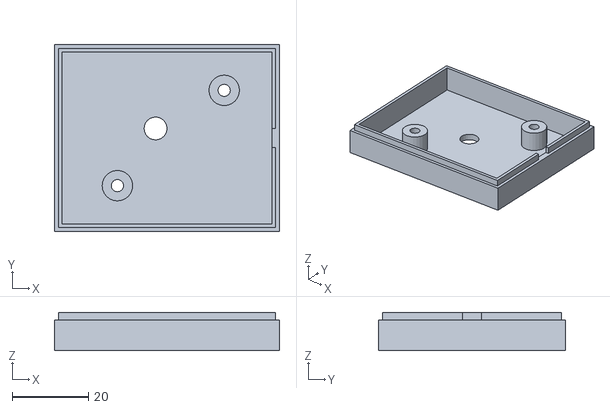
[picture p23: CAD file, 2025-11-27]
Tool Software/RFID Chip Scanner/PN532 Windows/3D FTDI ObenF.stl
59.0 x 49.0 x 10.0

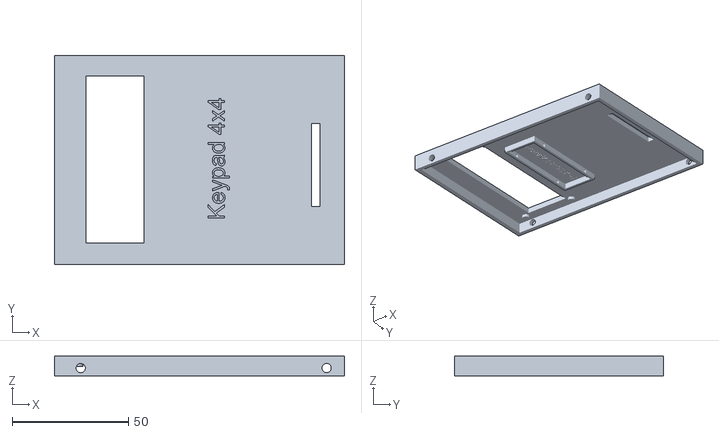
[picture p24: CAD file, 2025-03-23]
3D Druckerteile/Version 1 Basic mit Zero/DeckelV2.stl
125.0 x 90.0 x 8.50

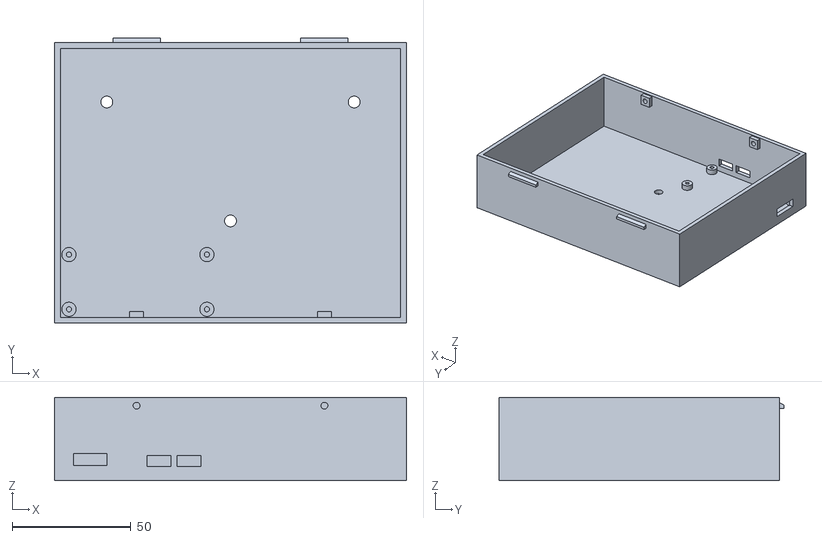
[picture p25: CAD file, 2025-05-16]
3D Druckerteile/Version 2 Standard mit Zero/DigiFlugbuch Unterteil.stl
148.0 x 120.0 x 35.0

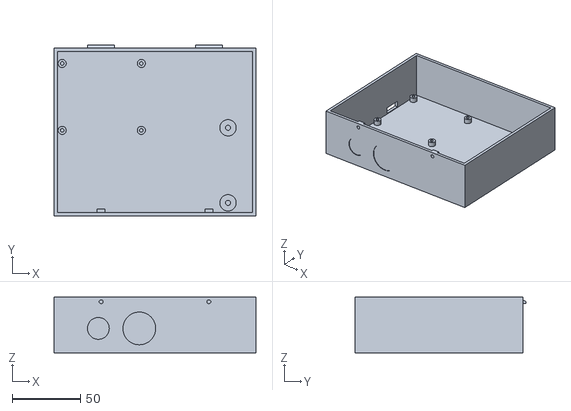
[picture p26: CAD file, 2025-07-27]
3D Druckerteile/Version 3 Deluxe mit PI4/DigiFlugbuch Rpi4 outdoor Gehäuse.stl
148.0 x 125.0 x 41.0

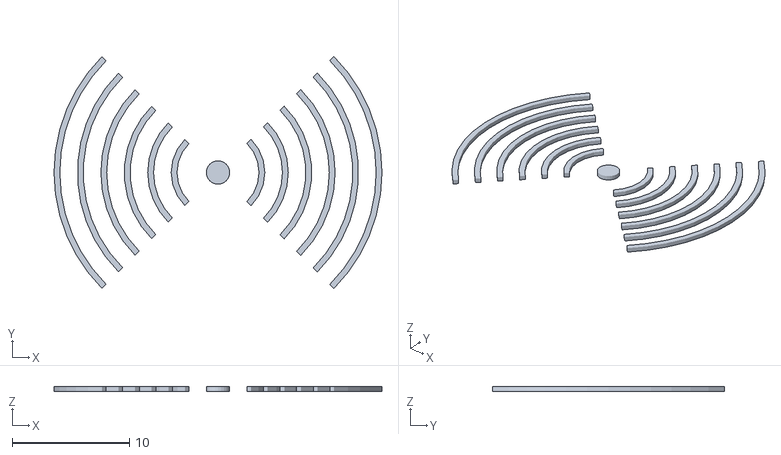
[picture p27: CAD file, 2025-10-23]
3D Druckerteile/Version 4 Deluxe mit PI5/Logo.stl
28.0 x 19.8 x 0.4

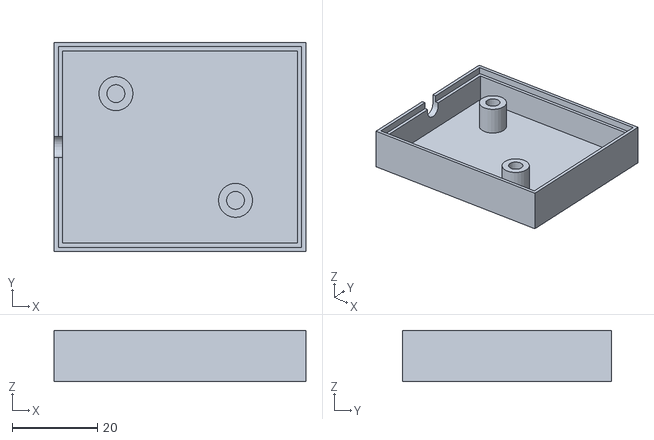
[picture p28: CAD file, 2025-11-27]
Tool Software/RFID Chip Scanner/PN532 Windows/3D FTDI Unten.stl
59.0 x 49.0 x 12.0

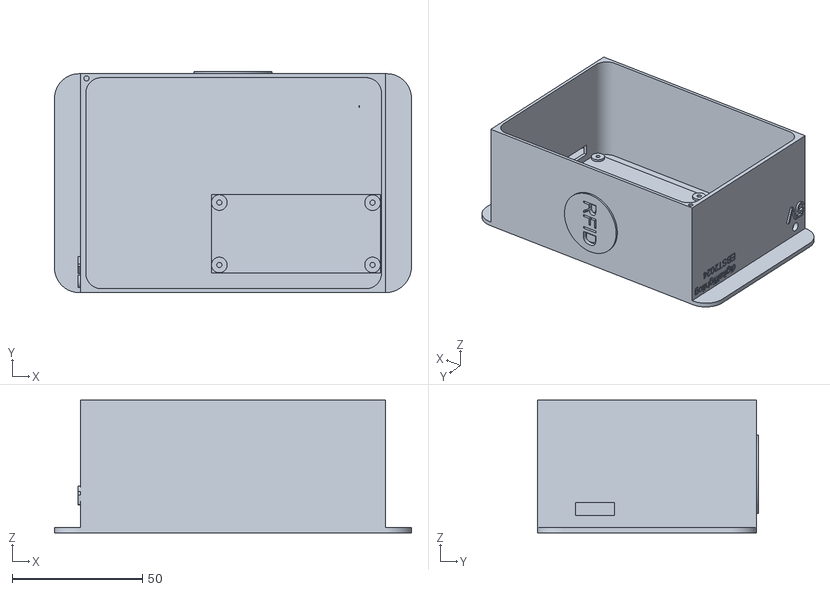
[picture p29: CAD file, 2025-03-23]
3D Druckerteile/Version 1 Basic mit Zero/GehäuseV2.stl
137.0 x 84.9 x 51.0

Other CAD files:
3D Druckerteile/Version 4 Deluxe mit PI5/mit SD Karten Serviceklappe/Gehäuse_PG16_unten+.stl
3D Druckerteile/Version 4 Deluxe mit PI5/Deckel_1_mit_Logo.stl
Tool Software/RFID Chip Scanner/PN532 Windows/3D FTDI Oben.stl
3D Druckerteile/Version 4 Deluxe mit PI5/Deckel_1_ohne_Logo.stl
3D Druckerteile/Version 4 Deluxe mit PI5/Deckel_2_mit_Logo.stl
3D Druckerteile/Version 4 Deluxe mit PI5/Deckel_2_ohne_Logo.stl
3D Druckerteile/Version 4 Deluxe mit PI5/Deckel_3_mit_Logo.stl
3D Druckerteile/Version 4 Deluxe mit PI5/Deckel_3_ohne_Logo.stl
3D Druckerteile/Version 4 Deluxe mit PI5/Gehäuse_PG16_oben.stl
3D Druckerteile/Version 4 Deluxe mit PI5/Gehäuse_PG16_unten.stl
3D Druckerteile/Zubehör/Tastatur/Tastatur Abdeckung.stl
Tool Software/RFID Chip Scanner/PN532 Windows/3D FTDI Fenster.stl

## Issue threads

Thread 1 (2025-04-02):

Tolles Projekt !

FARO-WebApplikationen, 2025-04-02:
Herzlichen Glückwunsch, wirklich tolles und gelungenes Projekt. Dazu kann man nur gratulieren !
Bitte weiterentwickeln und weiter so.

P.S.:
Bin schon gespannt, wie lange es dauert bis Fischer es kopiert, sein (c) draufsetzt und sich wieder wichtig macht.

stephanflug, 2025-04-02:
You're very welcome! Thank you for the kind words.

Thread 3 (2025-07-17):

Erfahrungsbericht Verein MCI

stephanflug, 2025-07-17:
Im Namen von Herrn Jenewein darf ich das hier veröffentlichen:

**Erfahrungsbericht zum Einsatz des digitalen Flugbuchs im Verein**

Als Verein möchten wir hier unsere Erfahrungen mit dem digitalen Flugbuch teilen, das von Stephan entwickelt und zur Verfügung gestellt wird. Ziel war es, eine zuverlässige, einfach bedienbare und kostengünstige Lösung zur Dokumentation unseres Flugbetriebs zu finden – und genau das haben wir mit diesem System erreicht.

**Umsetzung und Aufbau**
Wir haben uns für die Version 2 entschieden. Die notwendigen Bauteile wurden gemäß der Anleitung beschafft und nach dem offiziellen Schaltplan zusammengelötet. Dabei empfiehlt es sich, exakt an die vorgegebenen Punkte zu löten – ein kleiner Fehler bei der Verwendung eines Balancer-Steckers führte bei uns zu einem Wackelkontakt, konnte aber schnell behoben werden.

Das Gehäuse haben wir anhand der bereitgestellten STL-Dateien im 3D-Druck erstellt. Die Montage der Komponenten war unkompliziert – einige Teile wurden zusätzlich verklebt. Die Softwareinstallation auf dem Raspberry Pi erfolgte gemäß der GitHub-Anleitung mit dem Raspberry Pi Imager sowie dem Win32 Disk Imager. Der gesamte Ablauf war gut dokumentiert und funktionierte auf Anhieb.

**Funktion und Betrieb**
Nach dem Start erzeugt das System einen eigenen WLAN-Hotspot, über den sich Konfigurationen und Einstellungen bequem vornehmen lassen.

An unserem Flugplatz nutzen wir zusätzlich ein USB-Modem, über das am Monatsende automatisch die Flugdaten (CSV-Dateien) sowie ein Backup an eine definierte E-Mail-Adresse gesendet werden. Die Einrichtung des Mailversands hängt vom jeweiligen Anbieter ab, ist jedoch ebenfalls gut machbar.

Das System kann auch komplett offline betrieben werden. In diesem Fall ist ein Modul zur Zeitstabilisierung erforderlich, damit die Flüge korrekt datiert werden können.

**Erweiterungen und Softwarepflege**
Wer zusätzlich den Boss-Server einrichtet, profitiert von weiteren praktischen Funktionen. Die Daten können über FTP-Programme wie FileZilla auch auf eine Vereinswebsite (z. B. bei Lima City) übertragen werden.
Besonders positiv hervorzuheben ist, dass die Software aktiv weiterentwickelt wird. Updates lassen sich direkt über das Gerät installieren. Bei Problemen werden Spannung, Temperatur und WLAN-Stärke protokolliert, was die Fehlersuche enorm erleichtert.

Mit Version 3.5 wurde zudem die Option eingeführt, einen Höhensensor zu integrieren, der automatisch die Höhe und Anzahl der Flüge ans System überträgt – eine sehr hilfreiche Ergänzung.

**Fazit**
Das digitale Flugbuch ist eine durchdachte und stabile Lösung, die sich hervorragend für den Vereinsbetrieb eignet. Die Installation ist mit etwas technischem Verständnis gut machbar, die Kosten bleiben im Rahmen, und die Funktionalität überzeugt im täglichen Einsatz.

Unser Dank gilt Stephan für seine großartige Arbeit und die kontinuierliche Weiterentwicklung. Eine kleine Spende für die Kaffeekasse ist bei dieser Leistung absolut angebracht.

**MCI Modellbauclub Imst**
Kontaktperson: Gerhard Jenewein

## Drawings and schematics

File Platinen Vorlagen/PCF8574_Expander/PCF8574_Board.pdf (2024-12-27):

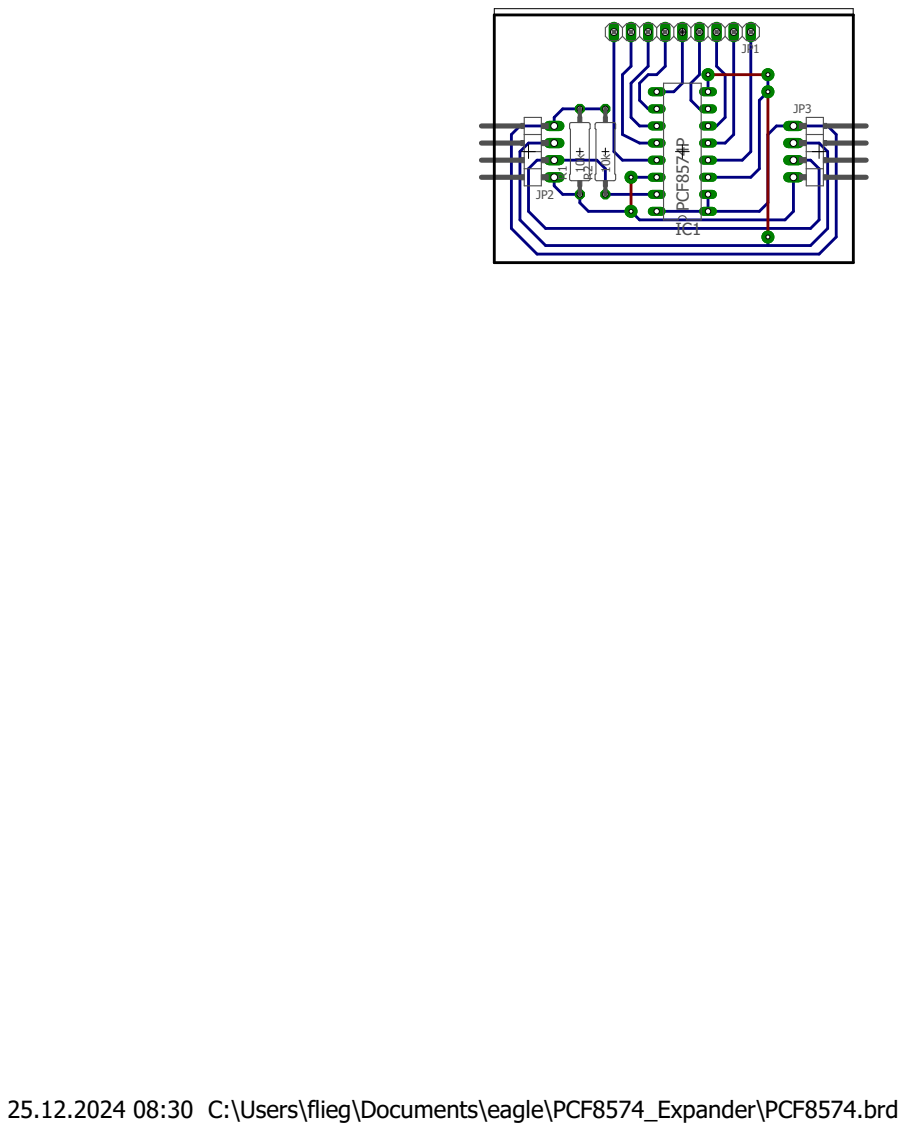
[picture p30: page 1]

25.12.2024 08:30 C:\Users\flieg\Documents\eagle\PCF8574_Expander\PCF8574.brd

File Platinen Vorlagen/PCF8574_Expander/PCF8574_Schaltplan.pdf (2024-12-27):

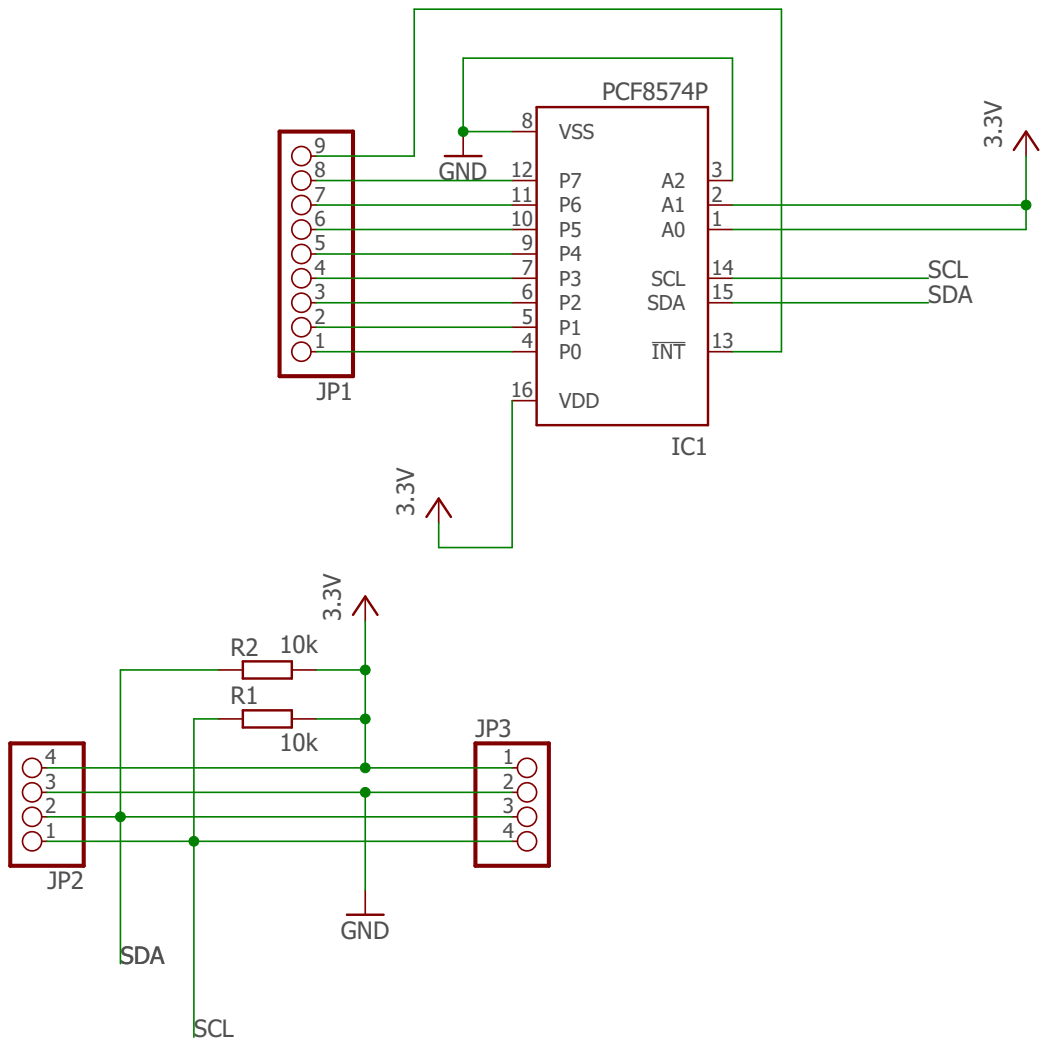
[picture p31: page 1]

Document Number: | REV:

Date: 25.12.2024 07:47 | Sheet: 1/1

25.12.2024 08:31 C:\Users\flieg\Documents\eagle\PCF8574_Expander\PCF8574.sch (Sheet: 1/1)

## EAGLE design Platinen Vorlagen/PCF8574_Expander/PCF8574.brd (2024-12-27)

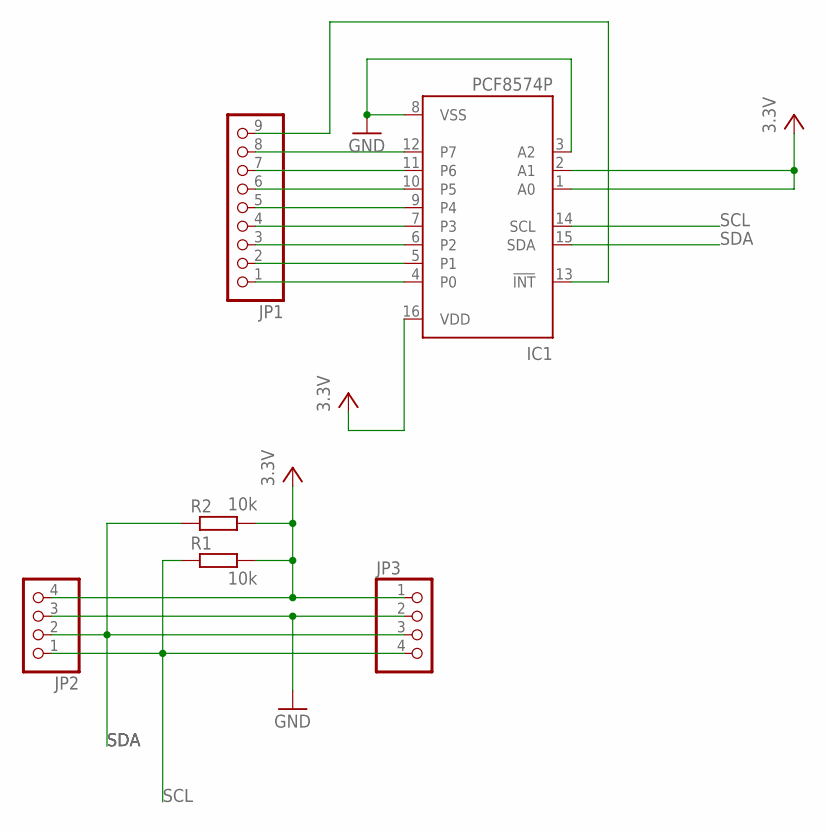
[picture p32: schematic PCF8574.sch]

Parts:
IC1: PCF8574P; DIL16
JP1: PINHD-1X9; 1X09
JP2, JP3: PINHD-1X4/90; 1X04/90
R1, R2: 10k; 0309/12

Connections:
GND: IC1.3 (A2), IC1.8 (VSS), JP2.3, JP3.2
unnamed: IC1.4 (P0), JP1.1
unnamed: IC1.5 (P1), JP1.2
unnamed: IC1.6 (P2), JP1.3
unnamed: IC1.7 (P3), JP1.4
unnamed: IC1.9 (P4), JP1.5
unnamed: IC1.10 (P5), JP1.6
unnamed: IC1.11 (P6), JP1.7
unnamed: IC1.12 (P7), JP1.8
unnamed: IC1.13 (!INT), JP1.9
SCL: IC1.14 (SCL), JP2.1, JP3.4, R1.1
SDA: IC1.15 (SDA), JP2.2, JP3.3, R2.1
VCC: IC1.1 (A0), IC1.2 (A1), IC1.16 (VDD), JP2.4, JP3.1, R1.2, R2.2

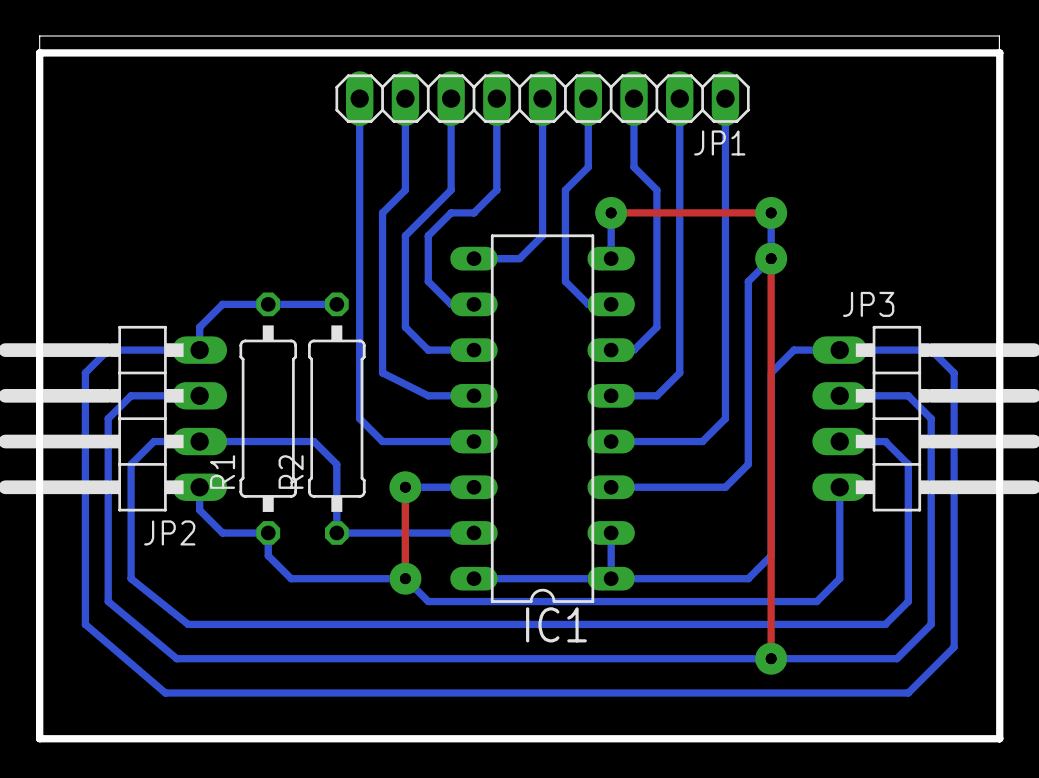
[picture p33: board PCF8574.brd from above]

Board: 2 copper layers, 53.3 x 39.0 mm, 6 parts (0 on the bottom side), 13 nets.
